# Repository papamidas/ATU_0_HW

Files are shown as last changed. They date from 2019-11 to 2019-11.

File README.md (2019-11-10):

# ATU_0_HW

Antenna Tuning Unit for Radio Amateurs:

- LC- or CL-type antenna tuner, software selectable
- 256 capacitance values: 0..2.5 nF in steps of 10 pF
- 256 inductance values	- 256 inductance values: 0..15 µH in steps of 60 nH
- controlled by an Arduino Nano
- powered by a USB power bank
- low current consumption (25..45 mA) by using bistable relays
- remote control via Bluetooth
- simple user interface using the Android app "serial bluetooth terminal"
- 10 memory buttons for recalling setups for different frequency bands
- open source hardware, open source firmware
	
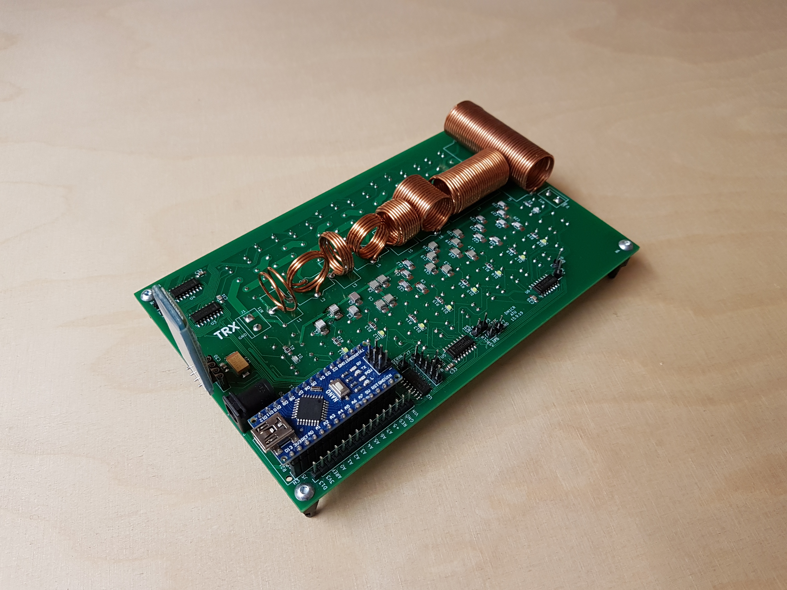
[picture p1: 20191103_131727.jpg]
ATU_0_TOP TOP

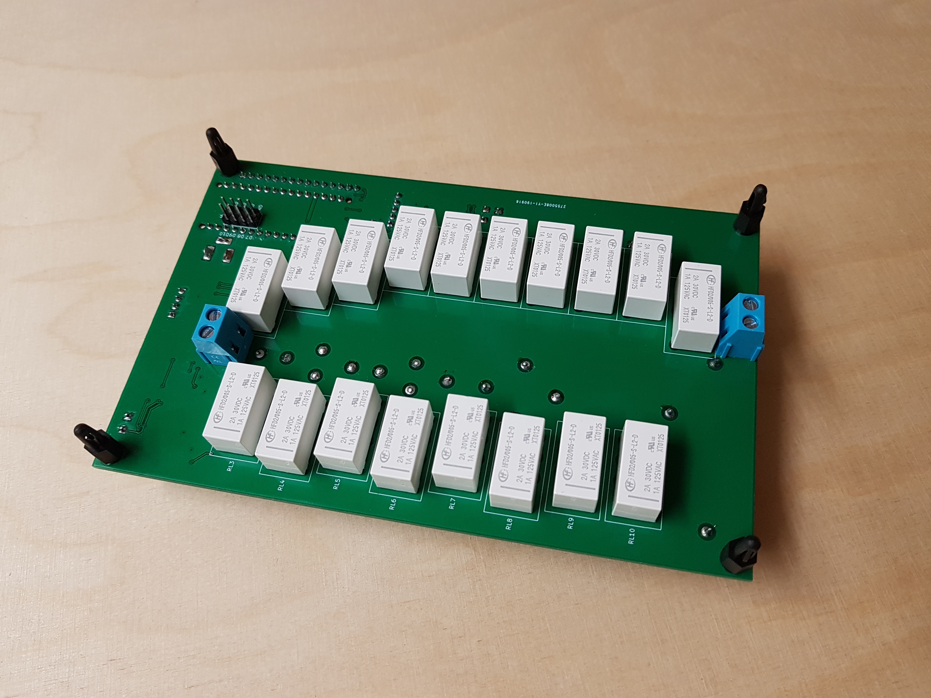
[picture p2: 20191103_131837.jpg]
ATU_0_BOTTOM BOTTOM


have fun!
73
papamidas (DM1CR)

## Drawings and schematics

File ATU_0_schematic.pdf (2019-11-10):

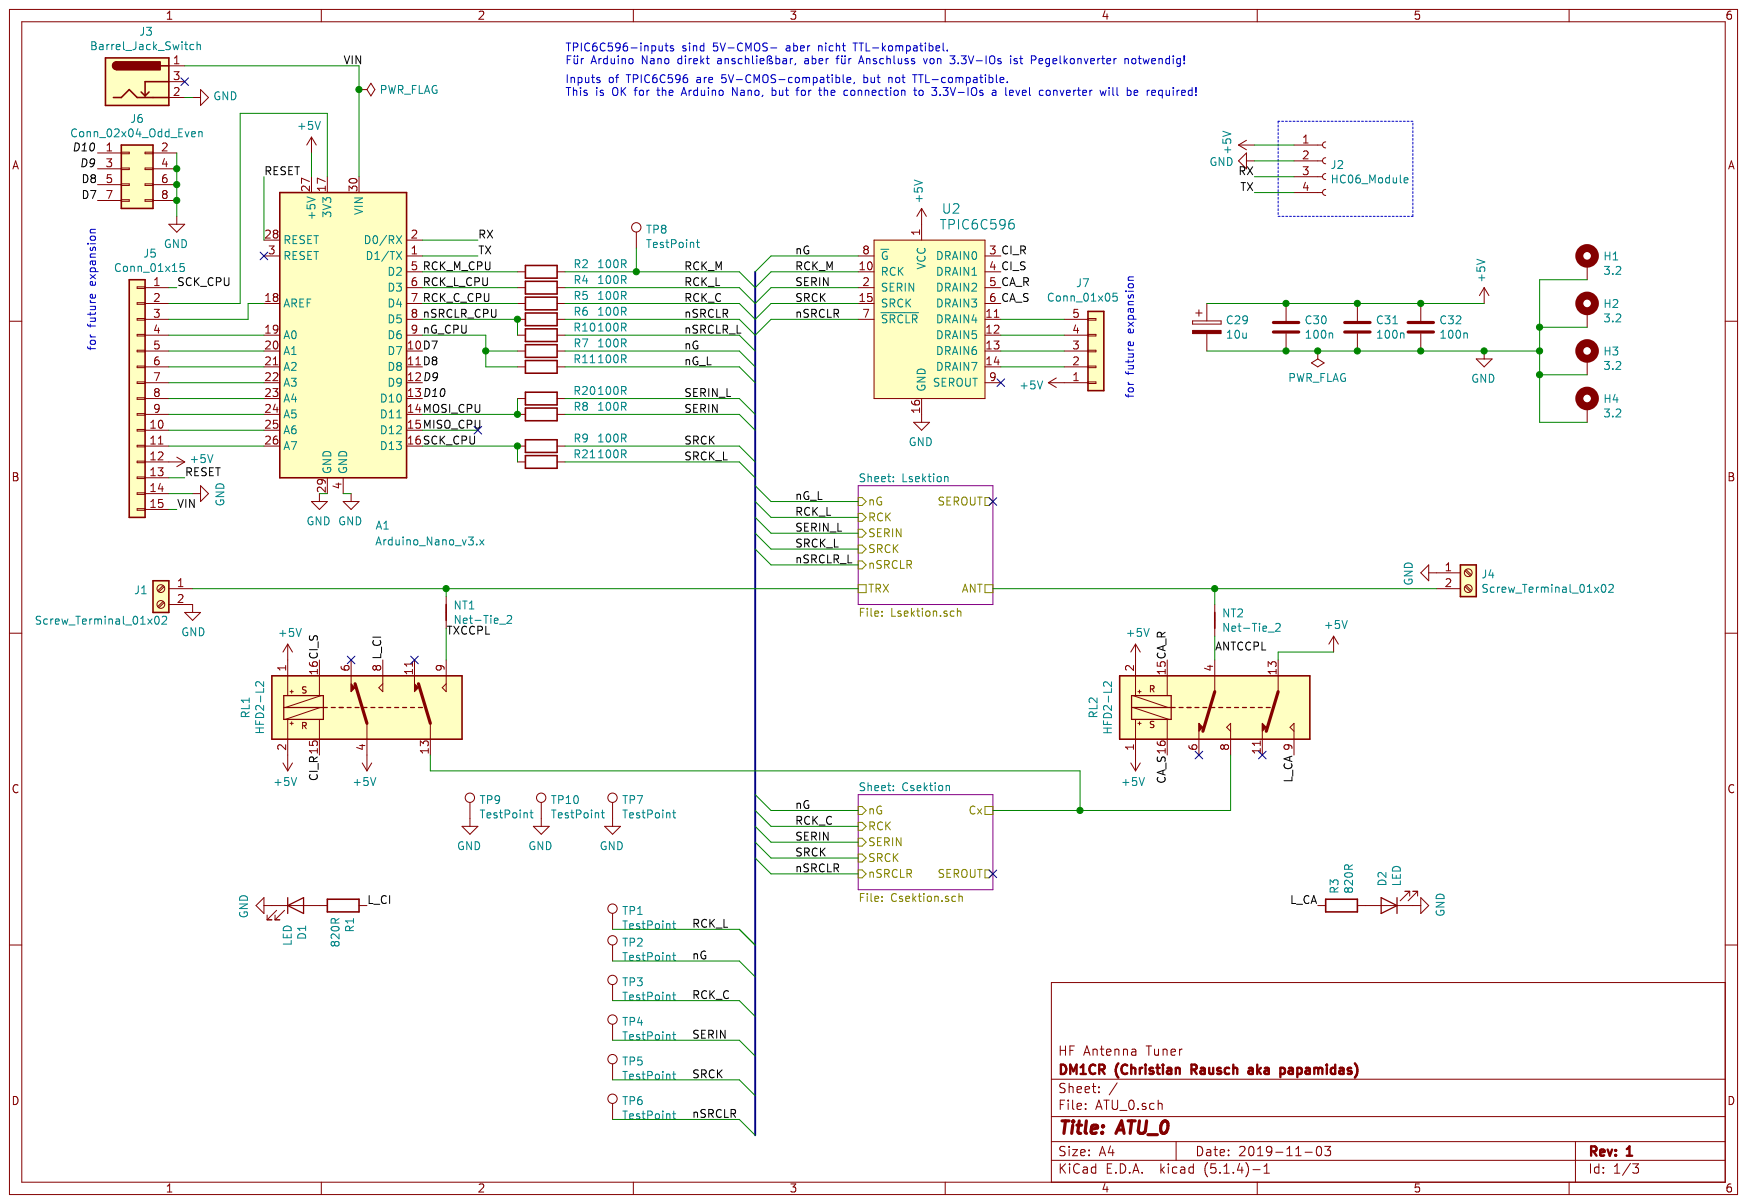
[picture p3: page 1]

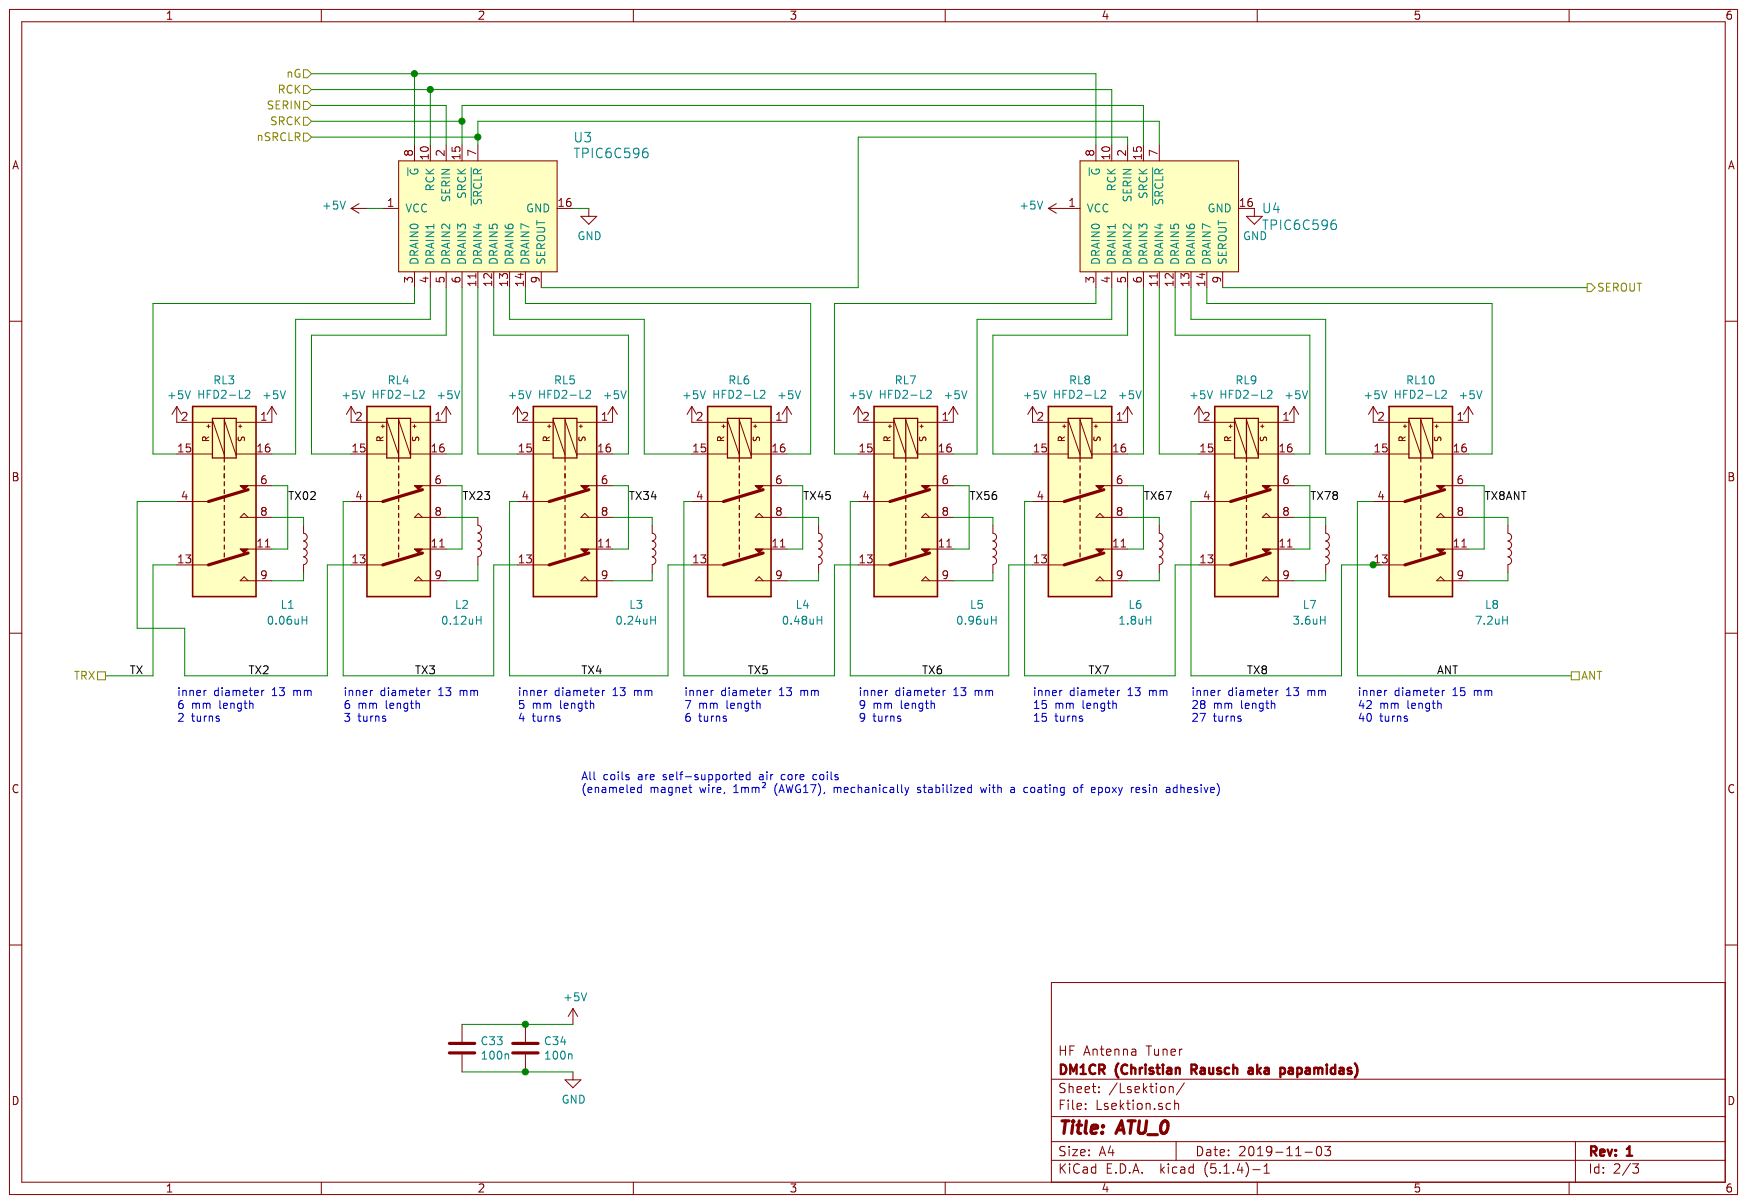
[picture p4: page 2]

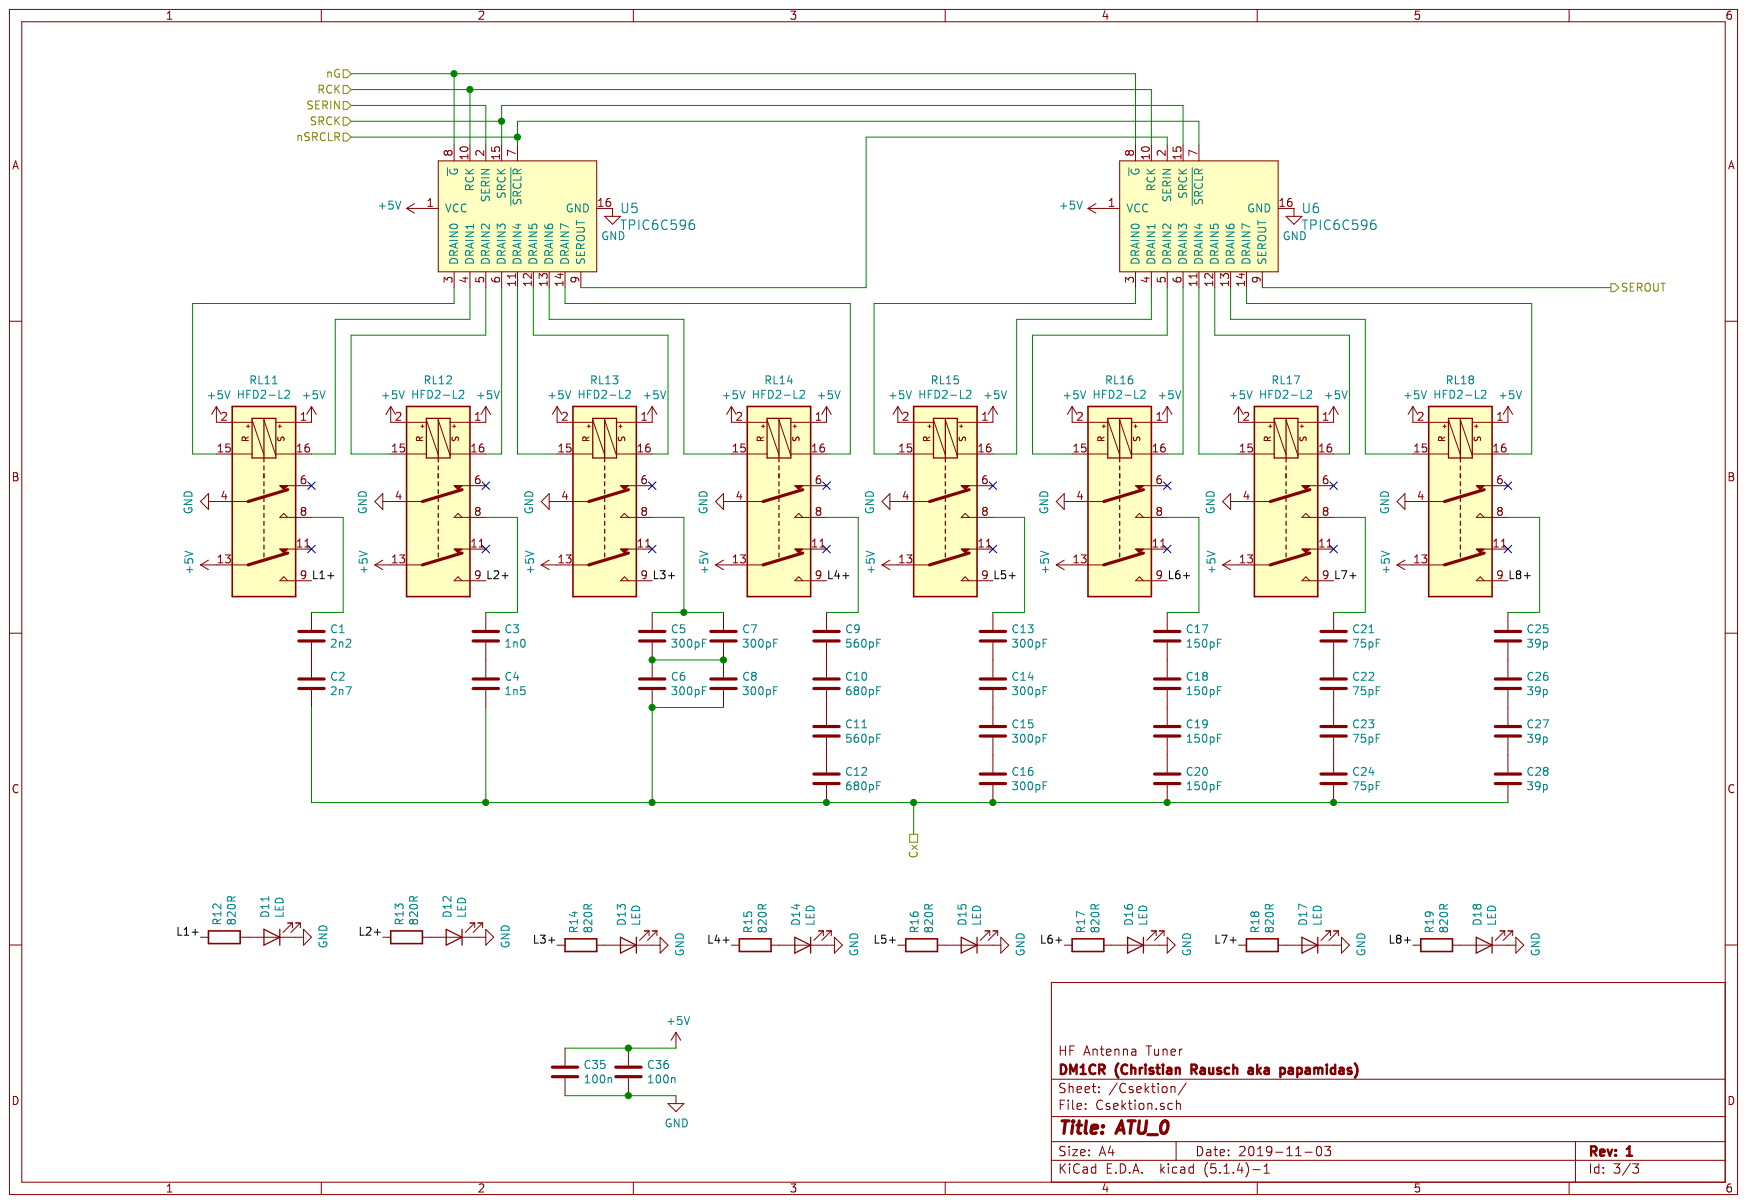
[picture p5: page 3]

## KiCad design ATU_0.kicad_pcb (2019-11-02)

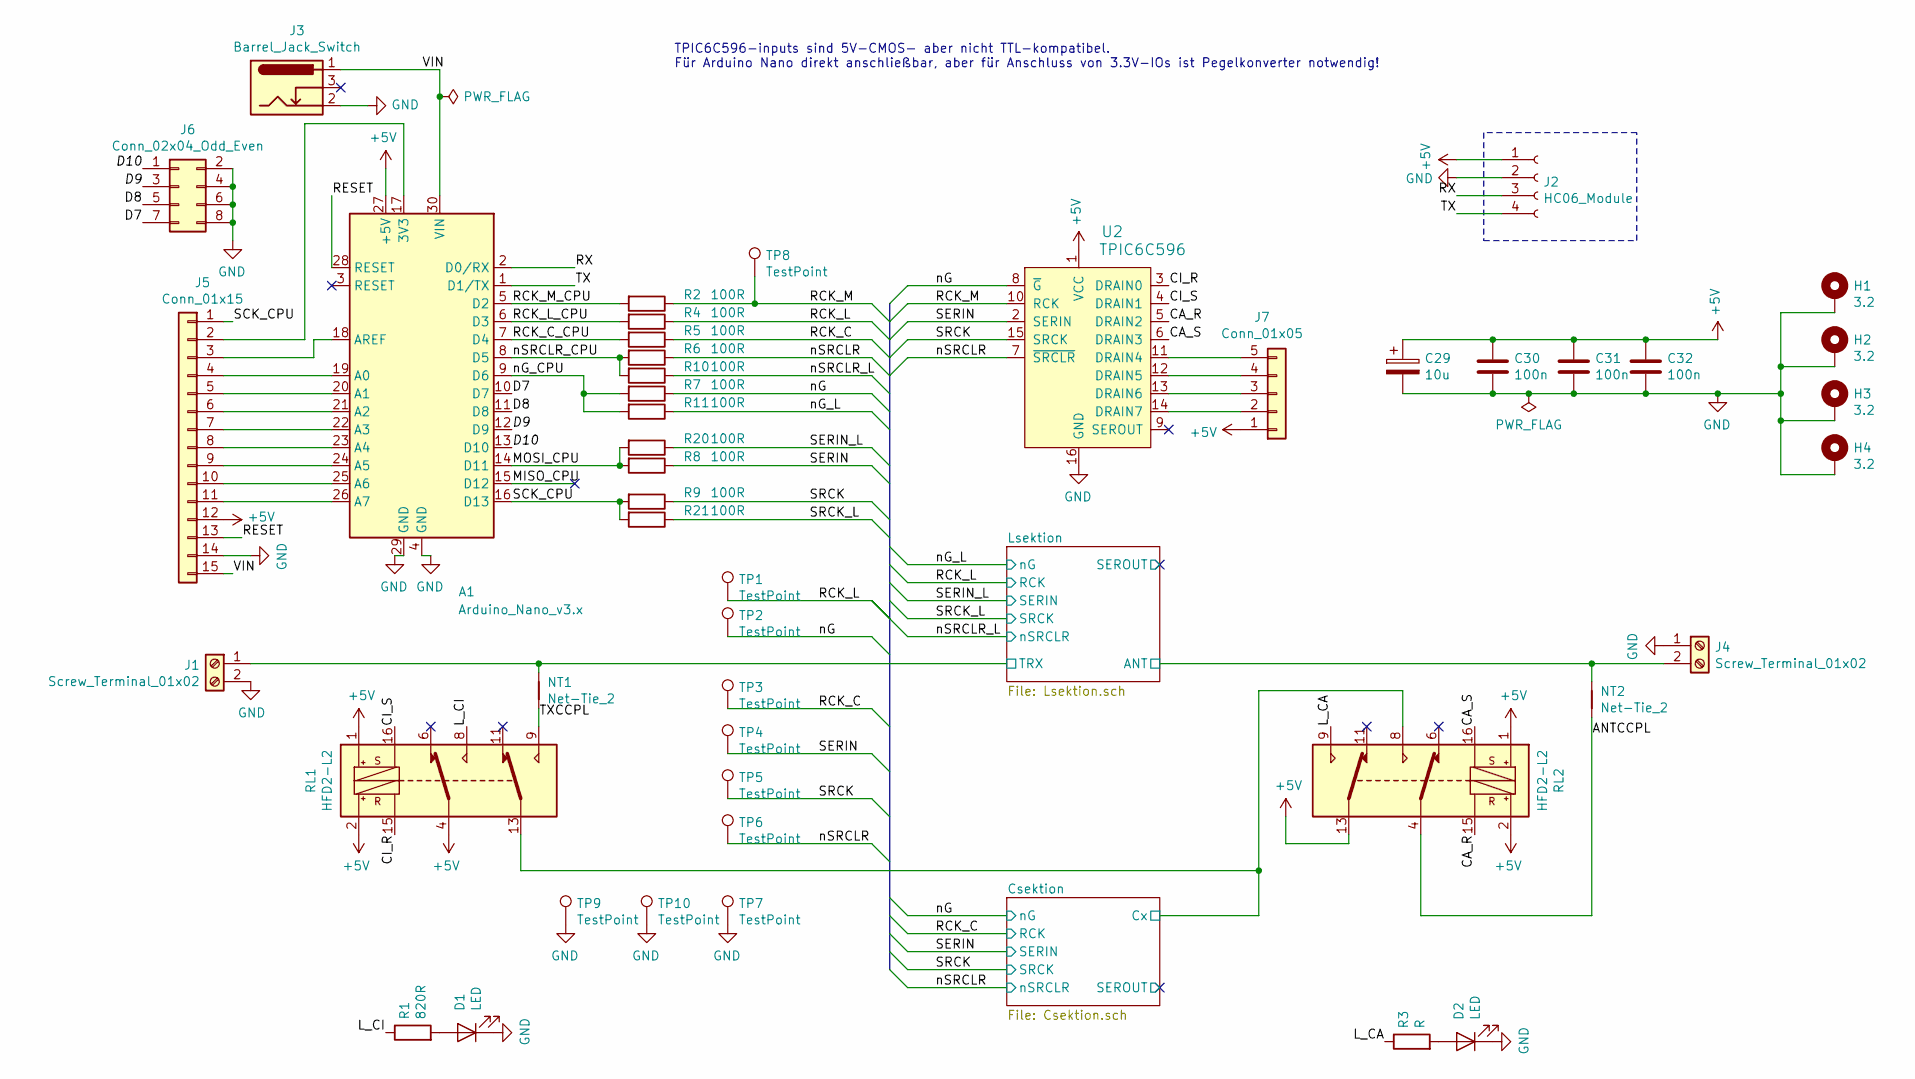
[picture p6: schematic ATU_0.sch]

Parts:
A1: Arduino_Nano_v3.x; Arduino_Nano_WithMountingHoles
C29: 10u; CP_Tantalum_Case-C_EIA-6032-28_Hand
C30, C31, C32: 100n; C_0805_HandSoldering
D1, D2: LED; D_0805
H1, H2, H3, H4: 3.2; MountingHole_3.2mm_M3_DIN965_Pad
J1, J4: Screw_Terminal_01x02; TerminalBlock_bornier-2_P5.08mm
J2: HC06_Module; Socket_Strip_Straight_1x04_Pitch2.54mm
J3: Barrel_Jack_Switch; Barrel_Jack_5.5mmODx2.1mmID_PJ-202A
J5: Conn_01x15; PinHeader_1x15_P2.54mm_Vertical
J6: Conn_02x04_Odd_Even; PinHeader_2x04_P2.54mm_Vertical
J7: Conn_01x05; PinHeader_1x05_P2.54mm_Vertical
NT1, NT2: Net-Tie_2; NetTie-2_SMD_Pad2.0mm
R1: 820R; R_0805_HandSoldering
R2, R4, R5, R6, R7, R8, R9, R10, R11, R20, R21: 100R; R_0805_HandSoldering
R3: R; R_0805_HandSoldering
RL1, RL2: HFD2-L2
TP1, TP2, TP3, TP4, TP5, TP6, TP7, TP8, TP9, TP10: TestPoint; PinHeader_1x01_P2.54mm_Vertical
U2: TPIC6C596; SOIC-16_W3.90mm; MPN TPIC6C596; Digi-Key_PN Mouser TPIC6C596DRQ1

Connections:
+5V: A1.27 (+5V), C29.1, C30.1, C31.1, C32.1, J2.1, J5.12, J7.1, RL1.1, RL1.2, RL1.4, RL2.1, RL2.2, RL2.13, U2.1 (VCC); also elsewhere on the board
/ANTCCPL: NT2.2, RL2.4
/CA_R: RL2.15, U2.5 (DRAIN2)
/CA_S: RL2.16, U2.6 (DRAIN3)
/CI_R: RL1.15, U2.3 (DRAIN0)
/CI_S: RL1.16, U2.4 (DRAIN1)
/Csektion/Cx: RL1.13, RL2.8; also elsewhere on the board
/D7: A1.10 (D7), J6.7
/D8: A1.11 (D8), J6.5
/D9: A1.12 (D9), J6.3
/D10: A1.13 (D10), J6.1
/L_CA: R3.1, RL2.9
/L_CI: R1.1, RL1.8
/Lsektion/ANT: J4.2, NT2.1; also elsewhere on the board
/Lsektion/TRX: J1.1, NT1.1; also elsewhere on the board
/MISO_CPU: A1.15 (D12)
/MOSI_CPU: A1.14 (D11), R8.2, R20.2
/RCK_C: R5.1, TP3.1; also elsewhere on the board
/RCK_C_CPU: A1.7 (D4), R5.2
/RCK_L: R4.1, TP1.1; also elsewhere on the board
/RCK_L_CPU: A1.6 (D3), R4.2
/RCK_M: R2.1, TP8.1, U2.10 (RCK)
/RCK_M_CPU: A1.5 (D2), R2.2
/RESET: A1.28 (RESET), J5.13
/RX: A1.2 (D0/RX), J2.3
/SCK_CPU: A1.16 (D13), J5.1, R9.2, R21.2
/SERIN: R8.1, TP4.1, U2.2 (SERIN); also elsewhere on the board
/SERIN_L: R20.1; also elsewhere on the board
/SRCK: R9.1, TP5.1, U2.15 (SRCK); also elsewhere on the board
/SRCK_L: R21.1; also elsewhere on the board
/TX: A1.1 (D1/TX), J2.4
/TXCCPL: NT1.2, RL1.9
/VIN: A1.30 (VIN), J3.1, J5.15
/nG: R7.1, TP2.1, U2.8 (~G); also elsewhere on the board
/nG_CPU: A1.9 (D6), R7.2, R11.2
/nG_L: R11.1; also elsewhere on the board
/nSRCLR: R6.1, TP6.1, U2.7 (~SRCLR); also elsewhere on the board
/nSRCLR_CPU: A1.8 (D5), R6.2, R10.2
/nSRCLR_L: R10.1; also elsewhere on the board
GND: A1.4 (GND), A1.29 (GND), C29.2, C30.2, C31.2, C32.2, D1.1 (K), D2.1 (K), H1.1, H2.1, H3.1, H4.1, J1.2, J2.2, J3.2, J4.1, J5.14, J6.2, J6.4, J6.6, J6.8, TP7.1, TP9.1, TP10.1, U2.16 (GND); also elsewhere on the board
unnamed: A1.17 (3V3), J5.2
unnamed: A1.18 (AREF), J5.3
unnamed: A1.19 (A0), J5.4
unnamed: A1.20 (A1), J5.5
unnamed: A1.21 (A2), J5.6
unnamed: A1.22 (A3), J5.7
unnamed: A1.23 (A4), J5.8
unnamed: A1.24 (A5), J5.9
unnamed: A1.25 (A6), J5.10
unnamed: A1.26 (A7), J5.11
unnamed: D1.2 (A), R1.2
unnamed: D2.2 (A), R3.2
unnamed: J7.2, U2.14 (DRAIN7)
unnamed: J7.3, U2.13 (DRAIN6)
unnamed: J7.4, U2.12 (DRAIN5)
unnamed: J7.5, U2.11 (DRAIN4)

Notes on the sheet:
TPIC6C596-inputs sind 5V-CMOS- aber nicht TTL-kompatibel. Für Arduino Nano direkt anschließbar, aber für Anschluss von 3.3V-IOs ist Pegelkonverter notwendig!

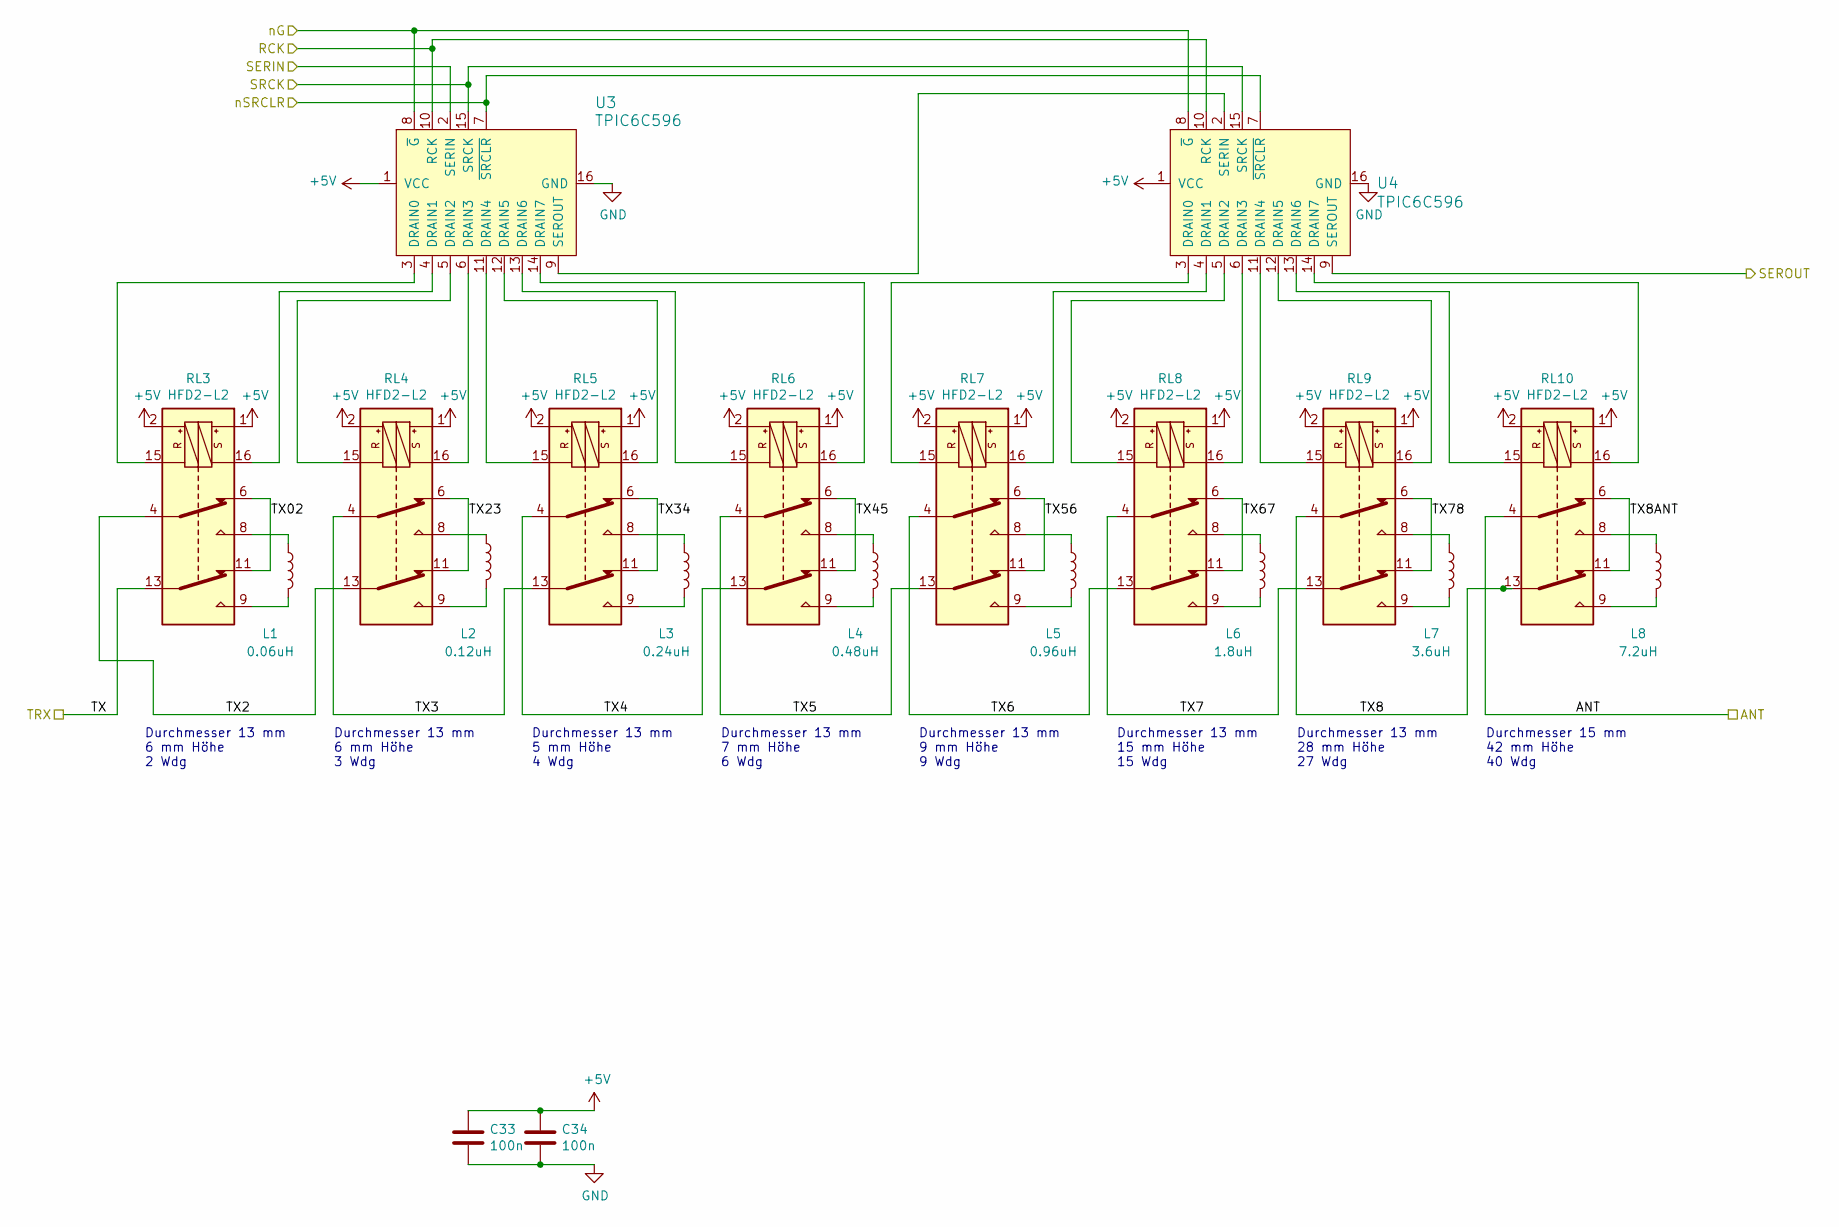
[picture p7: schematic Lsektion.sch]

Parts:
C33, C34: 100n; C_0805_HandSoldering
L1: 0.06uH; Aircoil_7_62_d15
L2: 0.12uH; Aircoil_7_62_d15
L3: 0.24uH; Aircoil_7_62_d15
L4: 0.48uH; Aircoil_7_62_d15
L5: 0.96uH; Aircoil_10_16_d15
L6: 1.8uH; Aircoil_15_24_d15
L7: 3.6uH; Aircoil_27_94_d15
L8: 7.2uH; Aircoil_43_18_d17
RL3, RL4, RL5, RL6, RL7, RL8, RL9, RL10: HFD2-L2
U3, U4: TPIC6C596; SOIC-16_W3.90mm; MPN TPIC6C596; Digi-Key_PN Mouser TPIC6C596DRQ1

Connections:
+5V: C33.1, C34.1, RL3.1, RL3.2, RL4.1, RL4.2, RL5.1, RL5.2, RL6.1, RL6.2, RL7.1, RL7.2, RL8.1, RL8.2, RL9.1, RL9.2, RL10.1, RL10.2, U3.1 (VCC), U4.1 (VCC); also elsewhere on the board
/Lsektion/ANT: RL10.4; also elsewhere on the board
/Lsektion/SEROUT: U4.9 (SEROUT)
/Lsektion/TRX: RL3.13; also elsewhere on the board
/Lsektion/TX2: RL3.4, RL4.13
/Lsektion/TX02: RL3.6, RL3.11
/Lsektion/TX3: RL4.4, RL5.13
/Lsektion/TX4: RL5.4, RL6.13
/Lsektion/TX5: RL6.4, RL7.13
/Lsektion/TX6: RL7.4, RL8.13
/Lsektion/TX7: RL8.4, RL9.13
/Lsektion/TX8: RL9.4, RL10.13
/Lsektion/TX8ANT: RL10.6, RL10.11
/Lsektion/TX23: RL4.6, RL4.11
/Lsektion/TX34: RL5.6, RL5.11
/Lsektion/TX45: RL6.6, RL6.11
/Lsektion/TX56: RL7.6, RL7.11
/Lsektion/TX67: RL8.6, RL8.11
/Lsektion/TX78: RL9.6, RL9.11
/RCK_L: U3.10 (RCK), U4.10 (RCK); also elsewhere on the board
/SERIN_L: U3.2 (SERIN); also elsewhere on the board
/SRCK_L: U3.15 (SRCK), U4.15 (SRCK); also elsewhere on the board
/nG_L: U3.8 (~G), U4.8 (~G); also elsewhere on the board
/nSRCLR_L: U3.7 (~SRCLR), U4.7 (~SRCLR); also elsewhere on the board
GND: C33.2, C34.2, U3.16 (GND), U4.16 (GND); also elsewhere on the board
unnamed: L1.1, RL3.8
unnamed: L1.2, RL3.9
unnamed: L2.1, RL4.8
unnamed: L2.2, RL4.9
unnamed: L3.1, RL5.8
unnamed: L3.2, RL5.9
unnamed: L4.1, RL6.8
unnamed: L4.2, RL6.9
unnamed: L5.1, RL7.8
unnamed: L5.2, RL7.9
unnamed: L6.1, RL8.8
unnamed: L6.2, RL8.9
unnamed: L7.1, RL9.8
unnamed: L7.2, RL9.9
unnamed: L8.1, RL10.8
unnamed: L8.2, RL10.9
unnamed: RL3.15, U3.3 (DRAIN0)
unnamed: RL3.16, U3.4 (DRAIN1)
unnamed: RL4.15, U3.5 (DRAIN2)
unnamed: RL4.16, U3.6 (DRAIN3)
unnamed: RL5.15, U3.11 (DRAIN4)
unnamed: RL5.16, U3.12 (DRAIN5)
unnamed: RL6.15, U3.13 (DRAIN6)
unnamed: RL6.16, U3.14 (DRAIN7)
unnamed: RL7.15, U4.3 (DRAIN0)
unnamed: RL7.16, U4.4 (DRAIN1)
unnamed: RL8.15, U4.5 (DRAIN2)
unnamed: RL8.16, U4.6 (DRAIN3)
unnamed: RL9.15, U4.11 (DRAIN4)
unnamed: RL9.16, U4.12 (DRAIN5)
unnamed: RL10.15, U4.13 (DRAIN6)
unnamed: RL10.16, U4.14 (DRAIN7)
unnamed: U3.9 (SEROUT), U4.2 (SERIN)

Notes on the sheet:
Durchmesser 13 mm 6 mm Höhe 2 Wdg
Durchmesser 13 mm 6 mm Höhe 3 Wdg
Durchmesser 13 mm 5 mm Höhe 4 Wdg
Durchmesser 13 mm 7 mm Höhe 6 Wdg
Durchmesser 13 mm 9 mm Höhe 9 Wdg
Durchmesser 13 mm 15 mm Höhe 15 Wdg
Durchmesser 13 mm 28 mm Höhe 27 Wdg
Durchmesser 15 mm 42 mm Höhe 40 Wdg

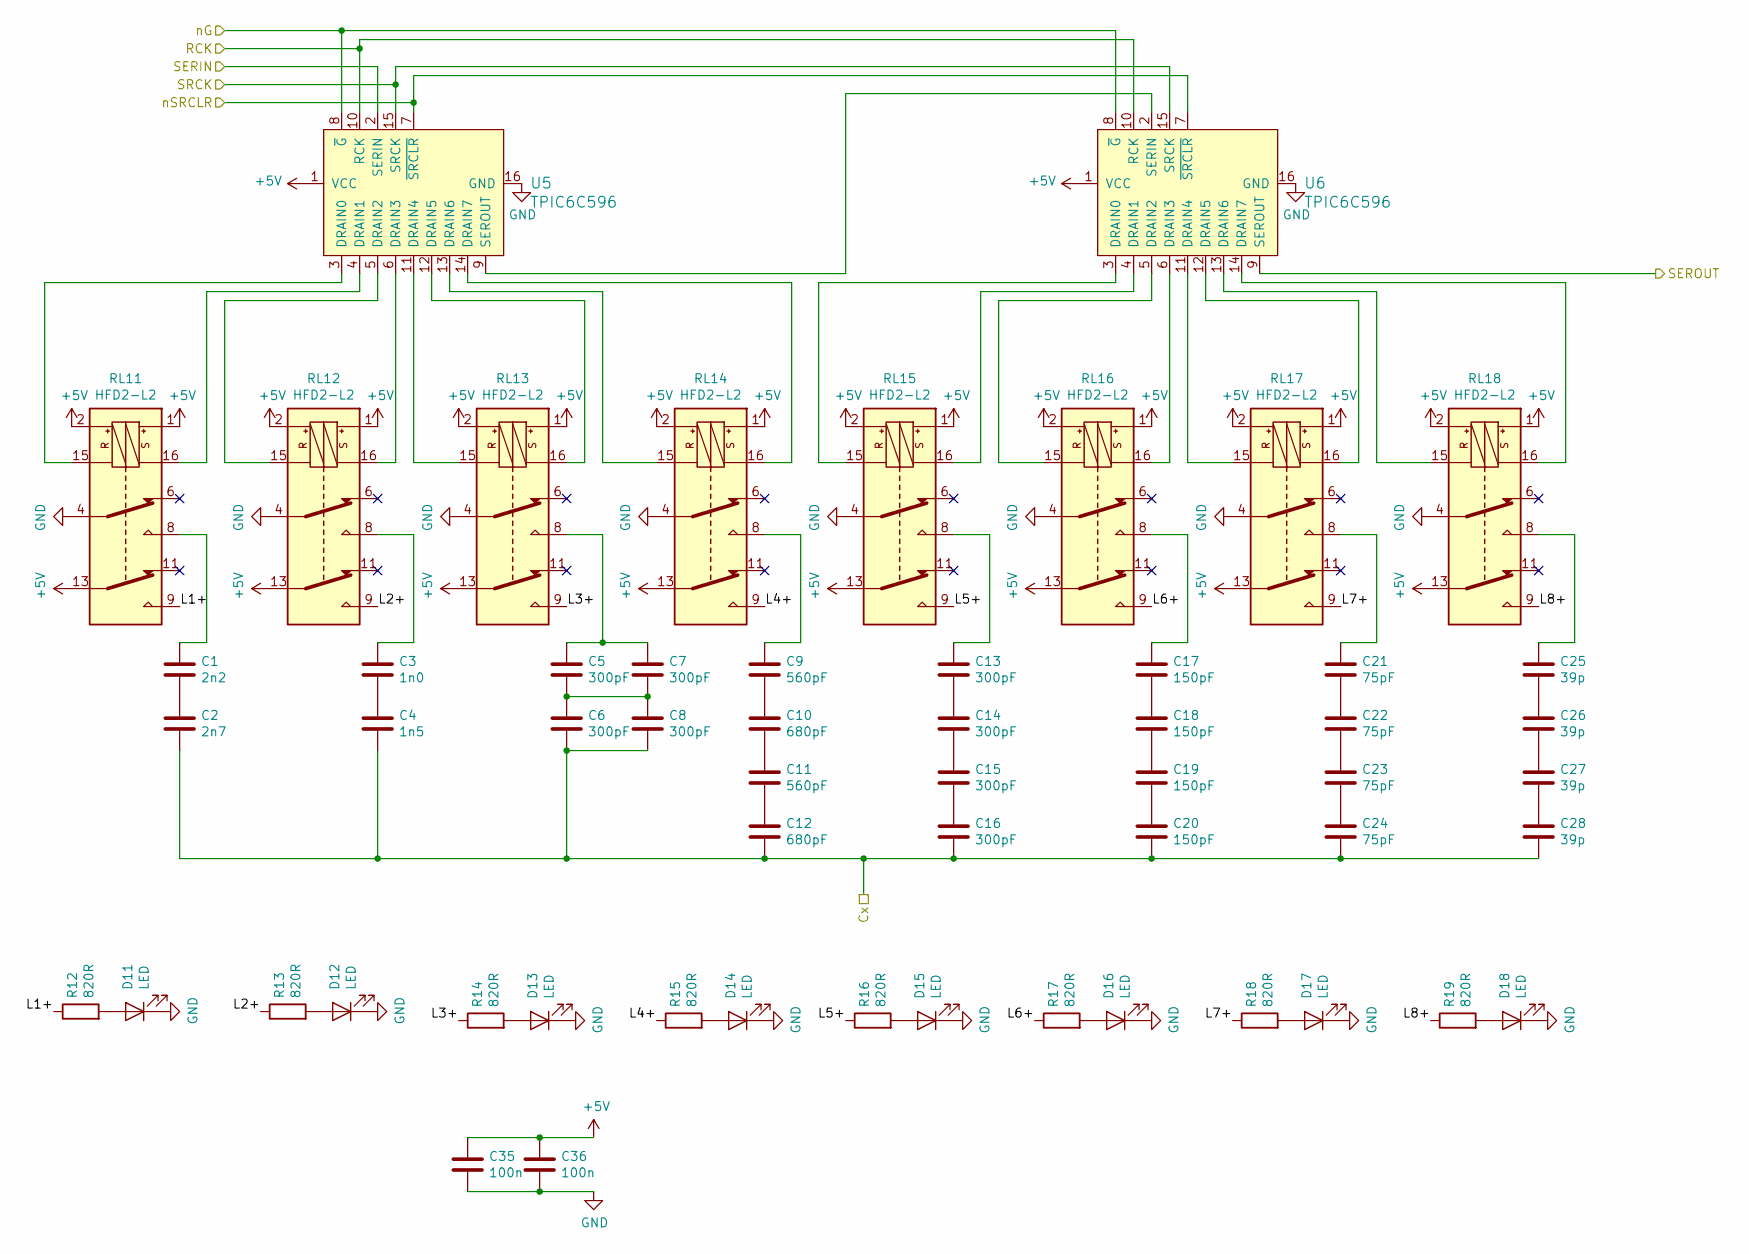
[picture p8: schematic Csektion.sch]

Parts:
C1: 2n2; C_1210_HandSoldering
C2: 2n7; C_1210_HandSoldering
C3: 1n0; C_1210_HandSoldering
C4: 1n5; C_1210_HandSoldering
C5, C6, C7, C8, C13, C14, C15, C16: 300pF; C_1210_HandSoldering
C9, C11: 560pF; C_1210_HandSoldering
C10, C12: 680pF; C_1210_HandSoldering
C17, C18, C19, C20: 150pF; C_1210_HandSoldering
C21, C22, C23, C24: 75pF; C_1210_HandSoldering
C25, C26, C27, C28: 39p; C_1210_HandSoldering
C35, C36: 100n; C_0805_HandSoldering
D11, D12, D13, D14, D15, D16, D17, D18: LED; D_0805
R12, R13, R14, R15, R16, R17, R18, R19: 820R; R_0805_HandSoldering
RL11, RL12, RL13, RL14, RL15, RL16, RL17, RL18: HFD2-L2
U5, U6: TPIC6C596; SOIC-16_W3.90mm; MPN TPIC6C596; Digi-Key_PN Mouser TPIC6C596DRQ1

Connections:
+5V: C35.1, C36.1, RL11.1, RL11.2, RL11.13, RL12.1, RL12.2, RL12.13, RL13.1, RL13.2, RL13.13, RL14.1, RL14.2, RL14.13, RL15.1, RL15.2, RL15.13, RL16.1, RL16.2, RL16.13, RL17.1, RL17.2, RL17.13, RL18.1, RL18.2, RL18.13, U5.1 (VCC), U6.1 (VCC); also elsewhere on the board
/Csektion/Cx: C2.2, C4.2, C6.2, C8.2, C12.2, C16.2, C20.2, C24.2, C28.2; also elsewhere on the board
/Csektion/L1+: R12.1, RL11.9
/Csektion/L2+: R13.1, RL12.9
/Csektion/L3+: R14.1, RL13.9
/Csektion/L4+: R15.1, RL14.9
/Csektion/L5+: R16.1, RL15.9
/Csektion/L6+: R17.1, RL16.9
/Csektion/L7+: R18.1, RL17.9
/Csektion/L8+: R19.1, RL18.9
/Csektion/SEROUT: U6.9 (SEROUT)
/RCK_C: U5.10 (RCK), U6.10 (RCK); also elsewhere on the board
/SERIN: U5.2 (SERIN); also elsewhere on the board
/SRCK: U5.15 (SRCK), U6.15 (SRCK); also elsewhere on the board
/nG: U5.8 (~G), U6.8 (~G); also elsewhere on the board
/nSRCLR: U5.7 (~SRCLR), U6.7 (~SRCLR); also elsewhere on the board
GND: C35.2, C36.2, D11.1 (K), D12.1 (K), D13.1 (K), D14.1 (K), D15.1 (K), D16.1 (K), D17.1 (K), D18.1 (K), RL11.4, RL12.4, RL13.4, RL14.4, RL15.4, RL16.4, RL17.4, RL18.4, U5.16 (GND), U6.16 (GND); also elsewhere on the board
unnamed: C1.1, RL11.8
unnamed: C1.2, C2.1
unnamed: C3.1, RL12.8
unnamed: C3.2, C4.1
unnamed: C5.1, C7.1, RL13.8
unnamed: C5.2, C6.1, C7.2, C8.1
unnamed: C9.1, RL14.8
unnamed: C9.2, C10.1
unnamed: C10.2, C11.1
unnamed: C11.2, C12.1
unnamed: C13.1, RL15.8
unnamed: C13.2, C14.1
unnamed: C14.2, C15.1
unnamed: C15.2, C16.1
unnamed: C17.1, RL16.8
unnamed: C17.2, C18.1
unnamed: C18.2, C19.1
unnamed: C19.2, C20.1
unnamed: C21.1, RL17.8
unnamed: C21.2, C22.1
unnamed: C22.2, C23.1
unnamed: C23.2, C24.1
unnamed: C25.1, RL18.8
unnamed: C25.2, C26.1
unnamed: C26.2, C27.1
unnamed: C27.2, C28.1
unnamed: D11.2 (A), R12.2
unnamed: D12.2 (A), R13.2
unnamed: D13.2 (A), R14.2
unnamed: D14.2 (A), R15.2
unnamed: D15.2 (A), R16.2
unnamed: D16.2 (A), R17.2
unnamed: D17.2 (A), R18.2
unnamed: D18.2 (A), R19.2
unnamed: RL11.15, U5.3 (DRAIN0)
unnamed: RL11.16, U5.4 (DRAIN1)
unnamed: RL12.15, U5.5 (DRAIN2)
unnamed: RL12.16, U5.6 (DRAIN3)
unnamed: RL13.15, U5.11 (DRAIN4)
unnamed: RL13.16, U5.12 (DRAIN5)
unnamed: RL14.15, U5.13 (DRAIN6)
unnamed: RL14.16, U5.14 (DRAIN7)
unnamed: RL15.15, U6.3 (DRAIN0)
unnamed: RL15.16, U6.4 (DRAIN1)
unnamed: RL16.15, U6.5 (DRAIN2)
unnamed: RL16.16, U6.6 (DRAIN3)
unnamed: RL17.15, U6.11 (DRAIN4)
unnamed: RL17.16, U6.12 (DRAIN5)
unnamed: RL18.15, U6.13 (DRAIN6)
unnamed: RL18.16, U6.14 (DRAIN7)
unnamed: U5.9 (SEROUT), U6.2 (SERIN)

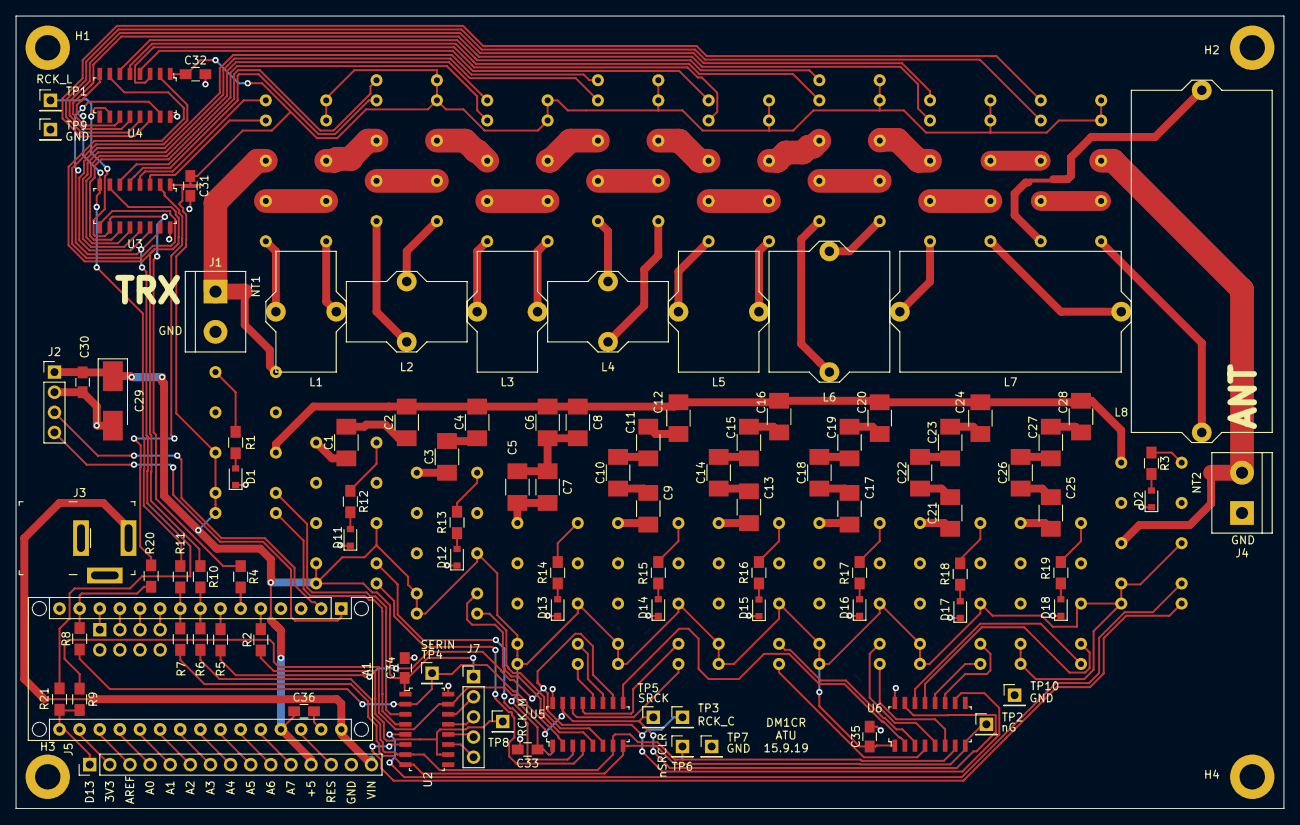
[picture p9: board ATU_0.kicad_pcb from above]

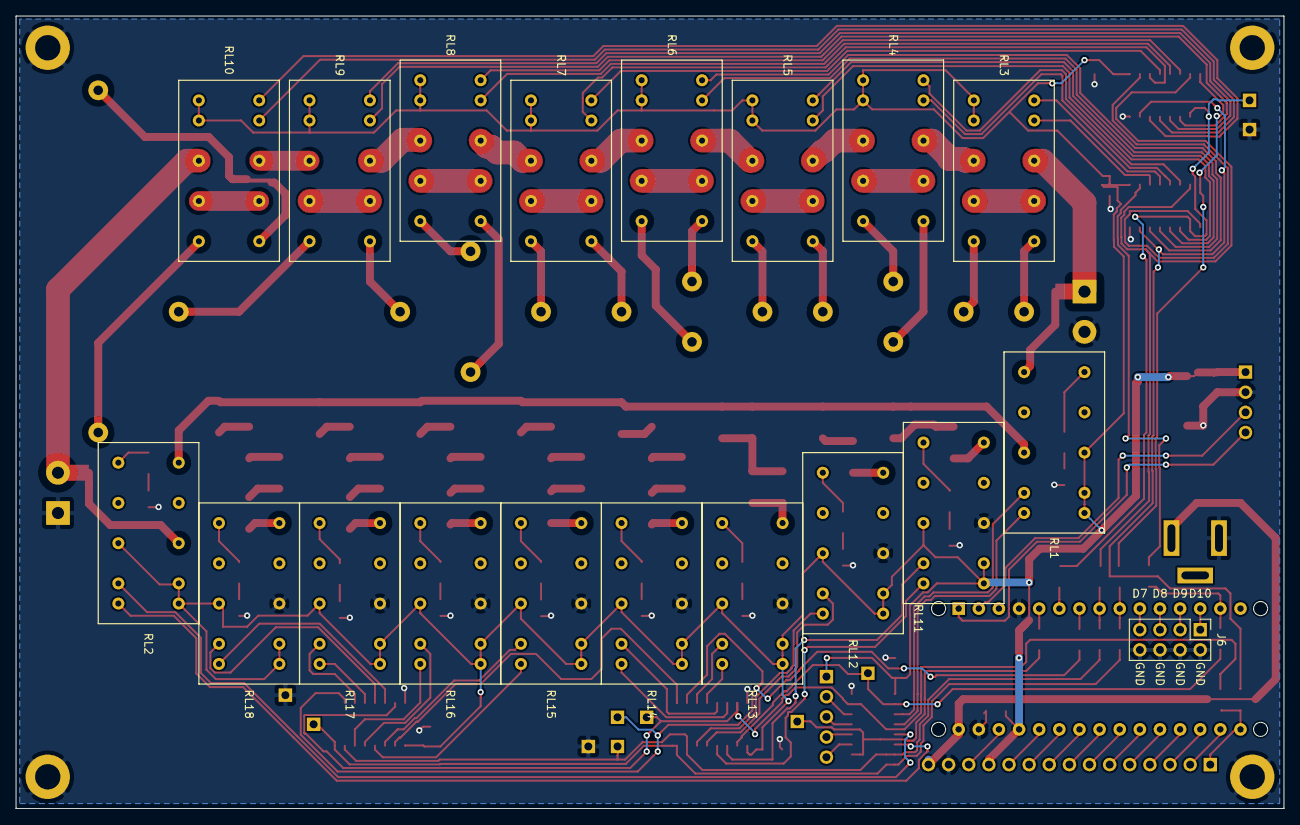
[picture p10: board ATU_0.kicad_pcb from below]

Board: 2 copper layers, 160.0 x 100.0 mm, 122 parts (19 on the bottom side), 162 nets.
